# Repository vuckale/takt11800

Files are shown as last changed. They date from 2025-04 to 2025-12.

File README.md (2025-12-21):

# takt11800 - Compaq MX 11800 QMK/VIA Replacement PCB
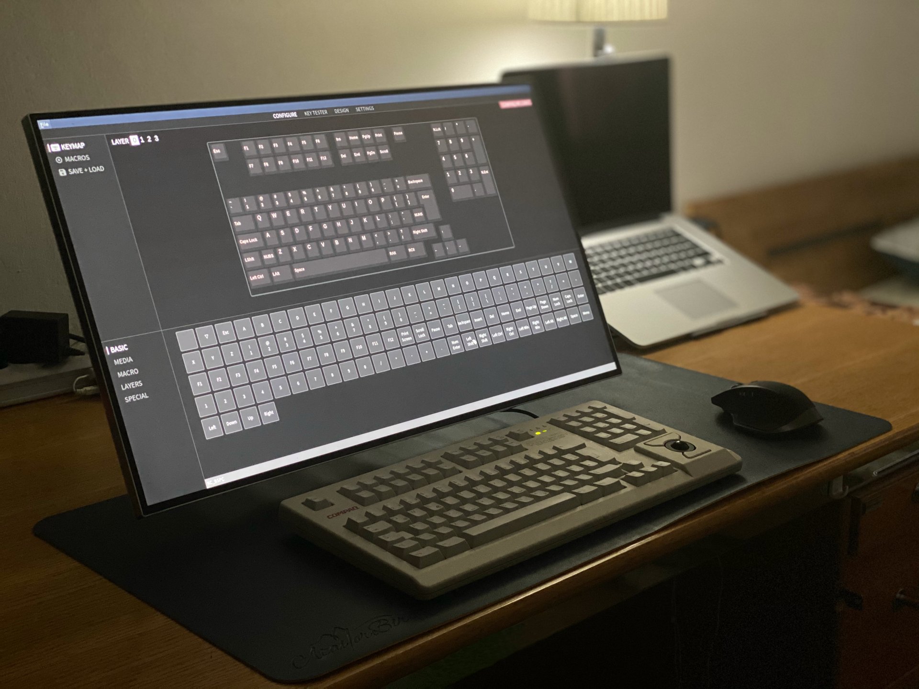
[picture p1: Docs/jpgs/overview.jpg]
Default Layout Overview


Sponsored by PCBWay - [Read More](#pcbway)

This project is a **drop-in replacement PCB** designed for the **Compaq MX 11800**, also known as the **Cherry G80-11800** a classic mechanical keyboard featuring **Cherry MX Brown switches** and an integrated **trackball**.

Originally designed for use in server rooms and rack-mounted setups, the MX 11800's **compact, space-saving layout** made it a go-to choice in enterprise environments.

### Project Features

- **Powered by QMK Firmware** – Fully customizable keymaps, layers, macros, and lighting effects.
- **VIA Support** – Seamless configuration through the user-friendly VIA interface.
- **Trackball Support** – Full functionality for the integrated pointing device.
- **Drop-In Compatible** – No case modifications required. Designed to fit directly into the original shell and work with original components.
- **USB-C Connectivity** – Modern convenience and reliability.

### Known Issues

During testing, the integrated trackball worked reliably with some MX 11800 variants (based on testing with a single German layout unit), but showed intermittent or unreliable behavior on others (such as international-layout versions). In some cases, the trackball would work inconsistently or fail to initialize.

At the time of writing, no reliable software solution has been found. Based on the observed behavior and the available hardware information, it is suspected that this may be related to a voltage level mismatch. The MCU operates at 3.3 V logic, while the original trackball assembly may expect 5 V logic levels. This has not yet been conclusively confirmed and remains under investigation.

A revised PCB is planned to address this potential issue at the hardware level. Until then, builders should be aware that trackball functionality may vary depending on the specific keyboard and trackball assembly used.

### BOM and CPL Orientation

The included BOM (Bill of Materials) and CPL (Component Placement List) are provided for orientation purposes. Depending on the assembly options selected and any variations in components, you may need to adjust these files when placing your order to ensure correct assembly.

### Why This Project?

The original MX 11800 has aged gracefully, but its internals were due for a modern upgrade. This replacement PCB brings this legendary board into the modern era while preserving its unique charm and functionality.

Whether you're a retro keyboard enthusiast, a server admin with a soft spot for classic gear, or just someone who loves trackball keyboards, this project gives new life to an iconic piece of hardware.

# Layout

## Default Layout
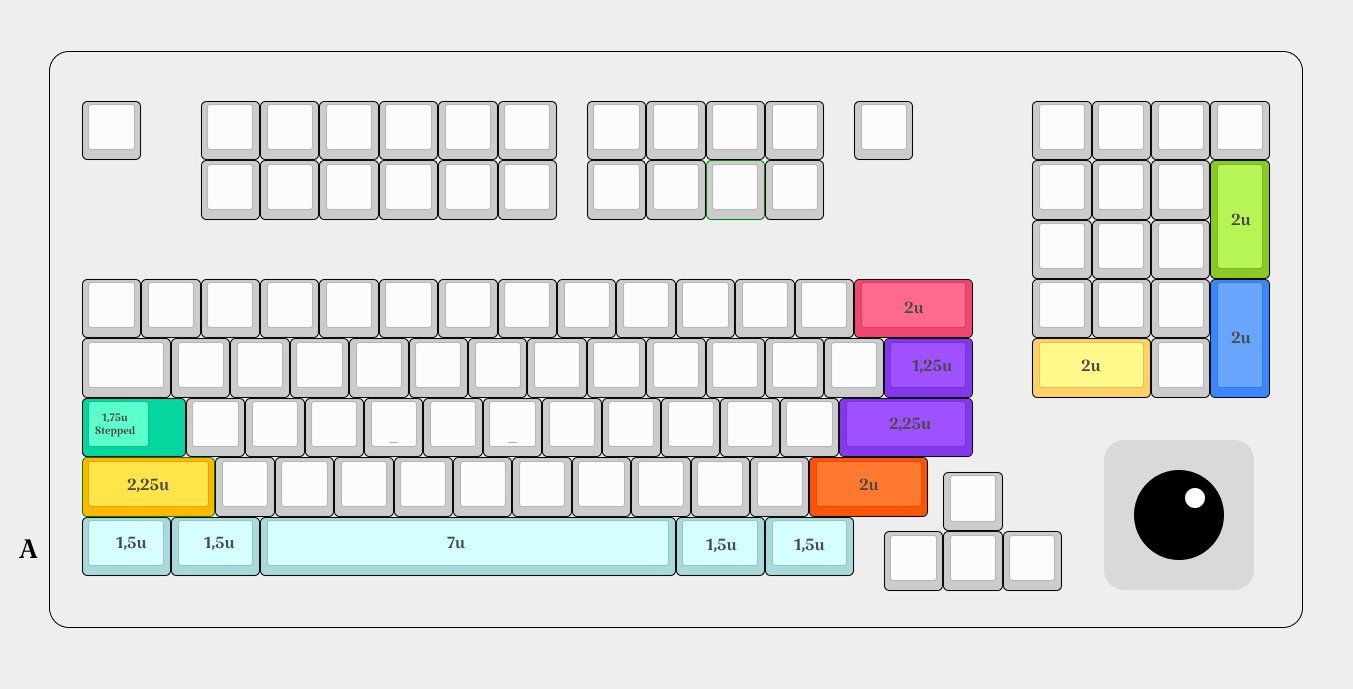
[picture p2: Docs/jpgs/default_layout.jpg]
Default Layout


This PCB supports multiple layout options. The previous image shows the default layout with colored keys and marked unit sizes that support alternate layouts. The default layout represents the configuration the keyboard is most commonly found in: ANSI enter with a 2.25u enter key, stepped caps lock, and a winkeyless 7u bottom row.

## Extended Layout
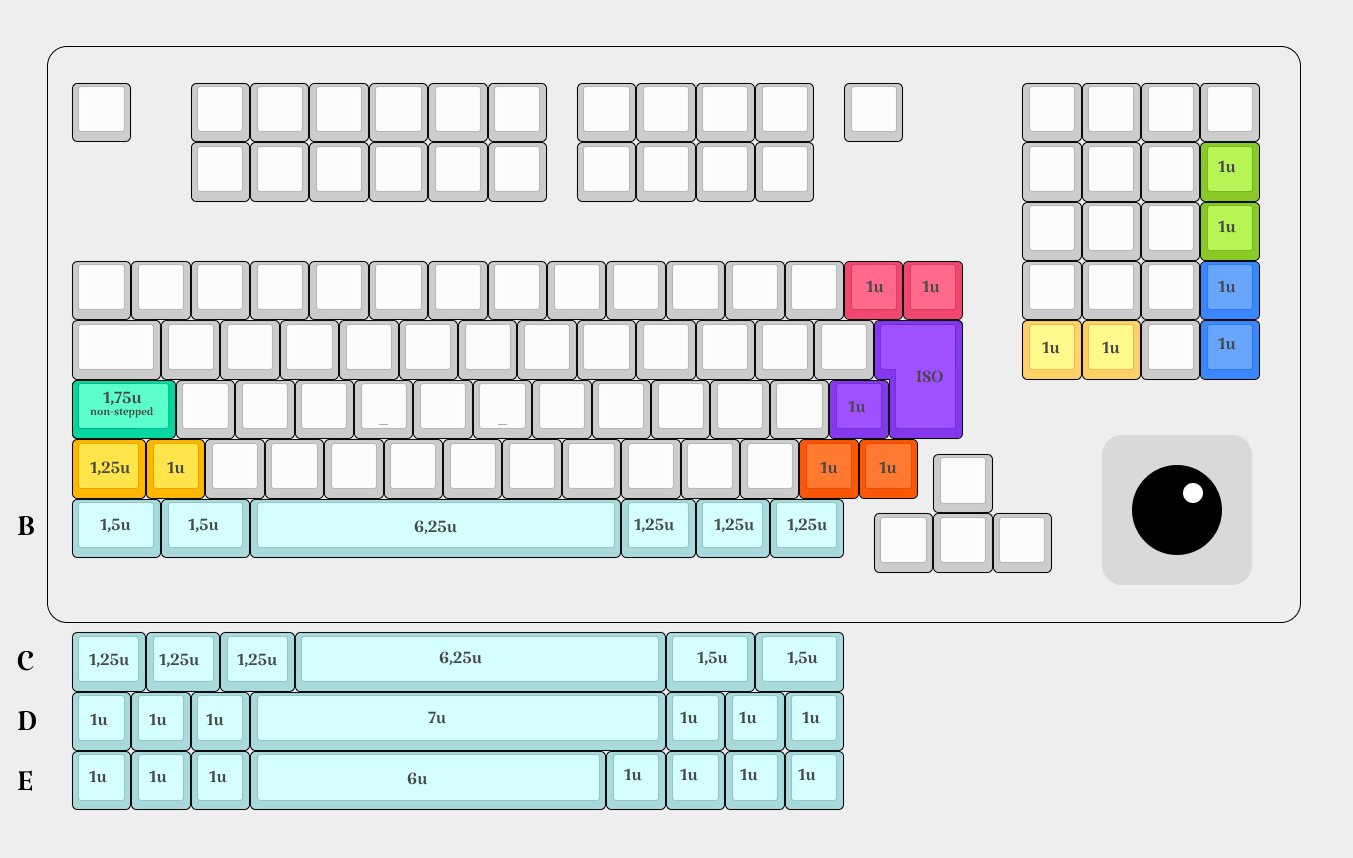
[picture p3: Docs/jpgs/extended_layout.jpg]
Extended Layout


The extended layout adds support for additional four bottom row variations, which are marked on the image with the letters b–e. For easier assembly, these are also labeled on the PCB itself, with unit sizes marked next to the switch holes and a–e marked on the stabilizer holes. Additionally, the extended layout supports a non-stepped caps lock key, ISO enter, split left shift and a backspace and 2u shift that can be split into two 1u keys. The numpad can also be converted into a full 1u macropad.

## PCB Overview
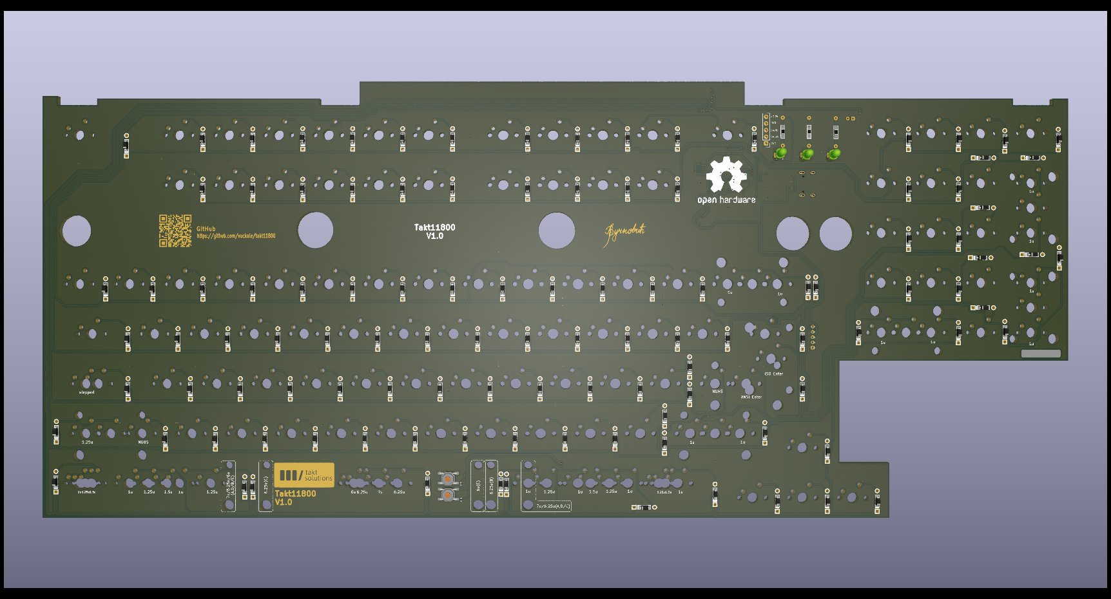
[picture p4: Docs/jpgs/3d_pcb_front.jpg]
Top View

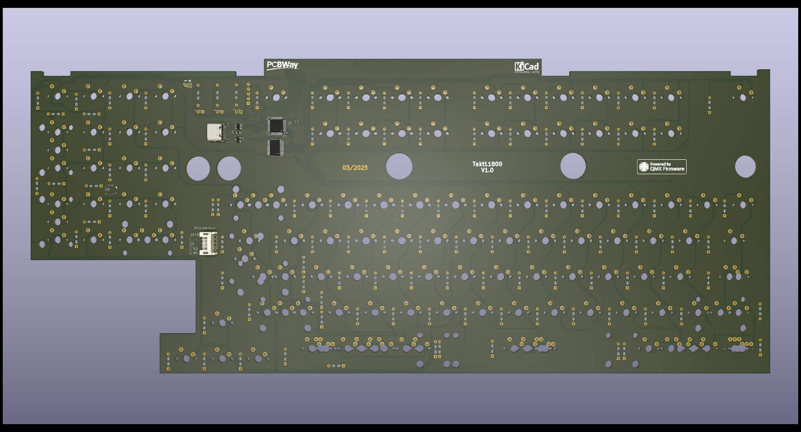
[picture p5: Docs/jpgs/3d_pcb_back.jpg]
Back View

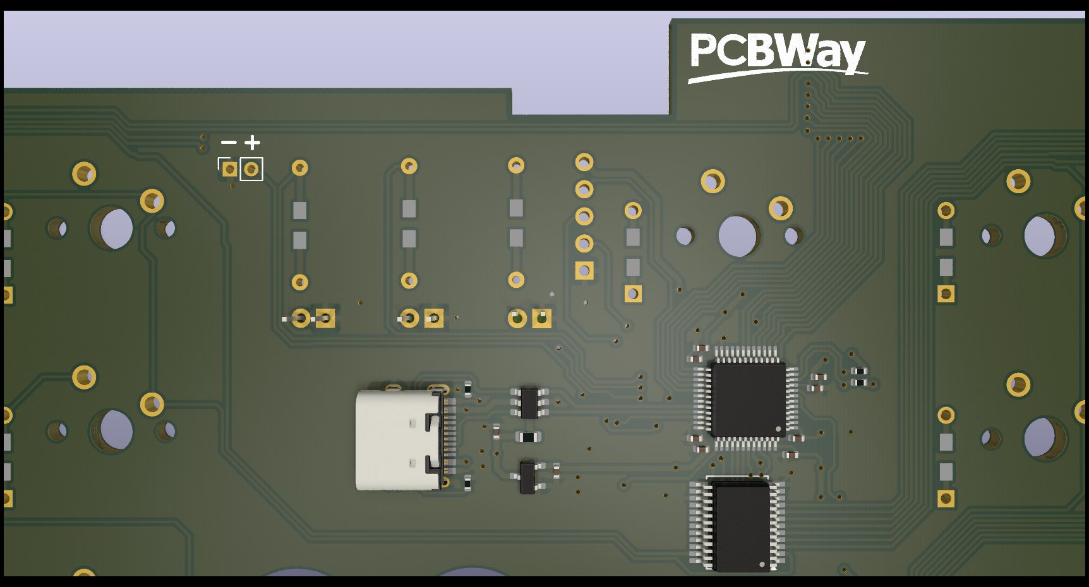
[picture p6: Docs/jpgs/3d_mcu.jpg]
MCU View

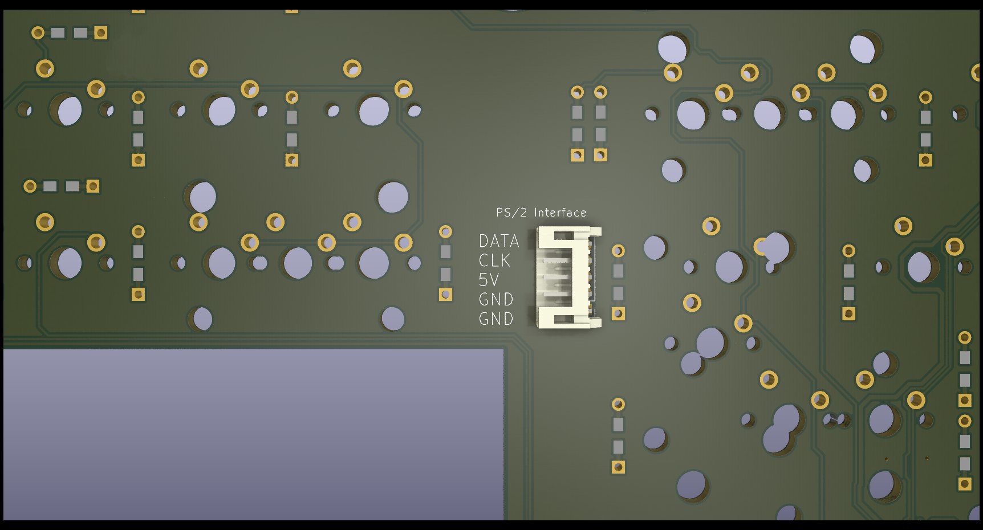
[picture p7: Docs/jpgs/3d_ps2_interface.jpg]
PS/2 Interface View


## PCBWay

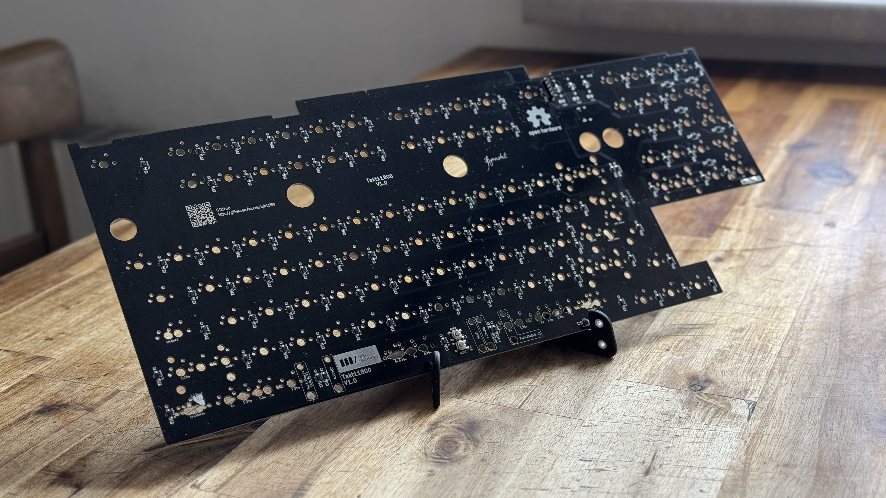
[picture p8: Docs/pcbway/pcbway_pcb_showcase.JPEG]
PCBWAY PCB Showcase


### Ordering Process

PCBWay made prototyping this PCB straightforward and easy. Their intuitive, beginner-friendly ordering process took all the guesswork out of manufacturing. I was impressed by how smoothly everything went, even on my first try. If you're curious to check it out or replicate the build, all the necessary files are neatly organized in the Fabrication Folder of this repository.

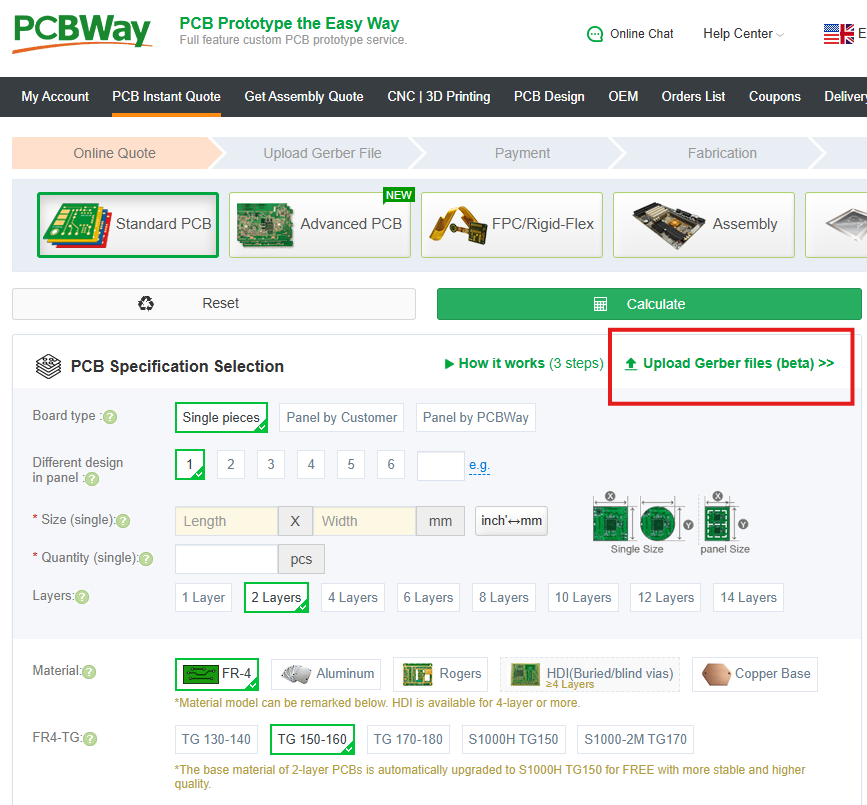
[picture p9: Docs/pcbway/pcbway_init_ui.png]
PCBWAY initial ui


Following the steps on their interface, placing an order with PCBWay was easy. After uploading the Gerber .zip file, the platform pre-filled many default values suitable for my 2-layer PCB, simplifying the process significantly. The only manual customization I initially made was changing the solder mask color to black—a purely aesthetic choice. However, PCBWay offers a wide range of specification options for those who want more control.

You can choose between single pieces, customer-designed panels, or panels assembled by PCBWay, and even combine different PCB designs within a single panel. Layer configurations are highly flexible, ranging from 1 up to 14 layers, with support for advanced materials like FR-4, Aluminum, and Rogers for high-frequency or thermal applications. PCB thickness can be set anywhere from 0.2 mm up to 3.2 mm, and you can define track/spacing resolutions as fine as 3/3 mil. For higher durability or signal performance, different finished copper weights are also available—ranging from bare copper to 12 oz Cu.

Solder mask colors include not only standard options like green, red, and blue, but also premium finishes like matte black and matte green. Silkscreen printing supports multiple colors (white, black, yellow) and even UV multi-color printing. Additional advanced options include edge connectors, various surface finishes like ENIG, immersion silver, and ENEPIG, and via treatments such as tenting, plugging, or open vias.

You also have the option to remove PCBWay's product number for a small fee, specify custom FR4-TG ratings, and opt for specialized features like castellated holes, edge plating, or impedance control. With all these configuration options, PCBWay caters not only to hobbyists but also to professionals needing precise and high-performance PCBs.

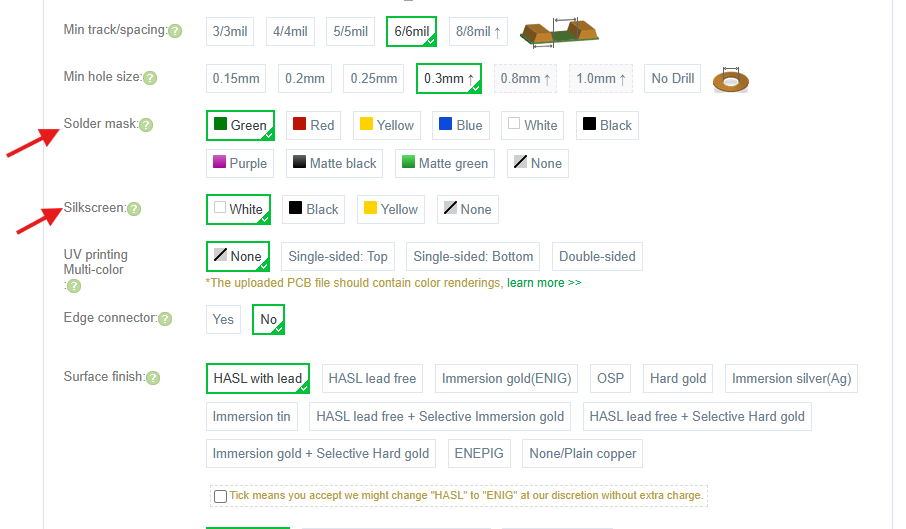
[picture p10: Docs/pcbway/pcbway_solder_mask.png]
PCBWAY solder mask color


For assembly, PCBWay provides a flexible set of options tailored to different needs: you can go with full turnkey assembly, where they source and solder everything; kitted/consigned, where you supply all the parts; or a combo option, where you send some components and let them handle the rest. 

For this project, I went with the full turnkey assembly—PCBWay not only assembled the boards but also sourced all the required components for me. This saved a huge amount of time and hassle, especially for parts that are hard to track down or have long lead times.

They also offer additional customization, like choosing whether to assemble single boards or panelized PCBs (recommended if you're doing runs of 20+ boards or working with small form factors), selecting top, bottom, or dual-sided assembly, and even specifying if you'd like to allow substitute components made in China—which I found useful for speeding up lead times without compromising quality.

Overall, their assembly service felt like a huge win—it was smooth, efficient, and let me focus entirely on design while they took care of the heavy lifting.

To do this, simply check the assembly option and fill in the necessary values as shown:

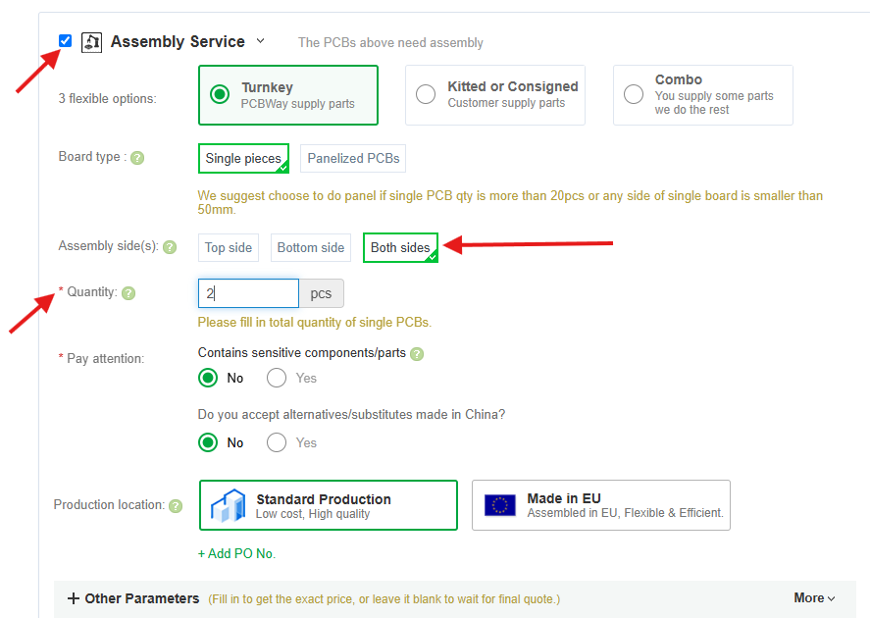
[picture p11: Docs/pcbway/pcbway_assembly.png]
PCBWAY assembly checkbox


After clicking "Save to Cart," you can upload the BOM, CPL, and component placement orientation files to complete your order.

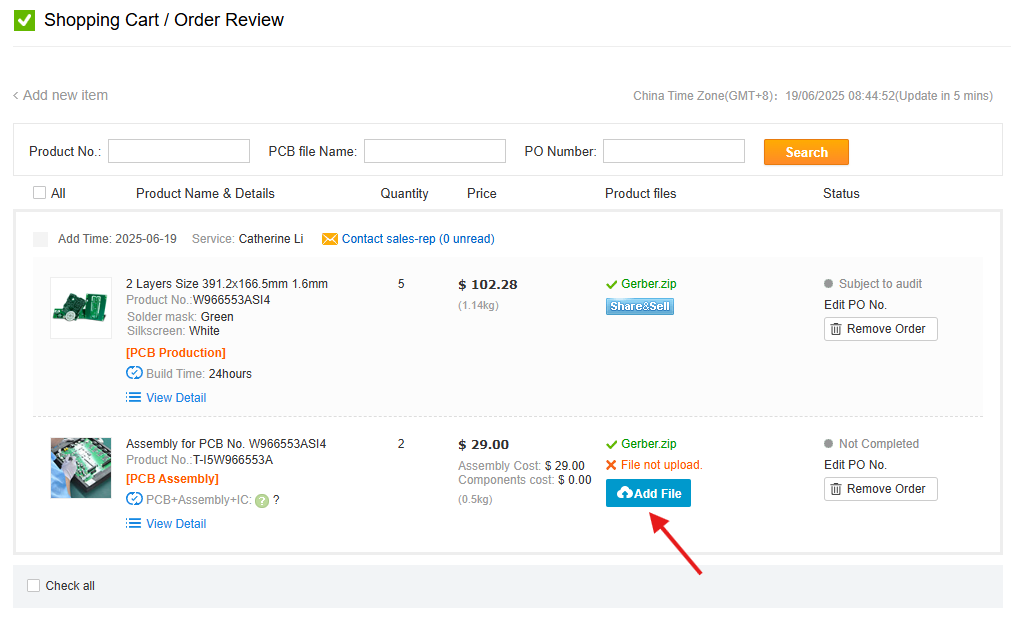
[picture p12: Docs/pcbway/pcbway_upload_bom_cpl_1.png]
PCBWAY Upload bom, cpl, and component placement orientation


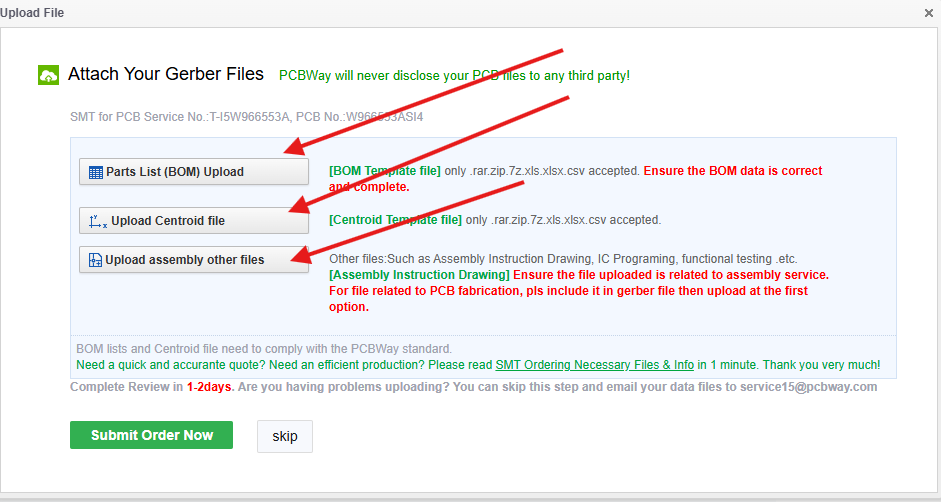
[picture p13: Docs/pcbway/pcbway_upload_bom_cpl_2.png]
PCBWAY Upload bom, cpl, and component placement orientation


After placing the order, I had frequent and helpful communication with their engineering team, who reached out to clarify a few design decisions and even helped me correct some mistakes in my Gerber files. I really appreciated how responsive and collaborative they were—it felt like working with a partner, not just a service provider.

One particularly thoughtful touch was that before final assembly and shipping, they sent me high-resolution photos of the finished PCBs for confirmation. This gave me a last opportunity to visually inspect the boards and ensure everything looked right—a great quality-control step that added to my confidence in the process.

Throughout production, PCBWay provides visual order tracking on their website, which shows exactly where your order is at every stage—file review, fabrication, solder mask, silkscreen, assembly, testing, and packaging. It’s clearly laid out and updated in real time, which made the waiting process far less stressful.

The total turnaround time was about two weeks, which included fabrication, full assembly, and component sourcing. When the package arrived, it was clear that shipping was handled with care: each board was sealed in an anti-static bag, then carefully wrapped with protective shrink wrap and cushioning to prevent any damage during transit.

Overall, the combination of attentive support, visual transparency, and high-quality results made the whole experience smooth and satisfying. I wouldn’t hesitate to work with them again on future prototypes.

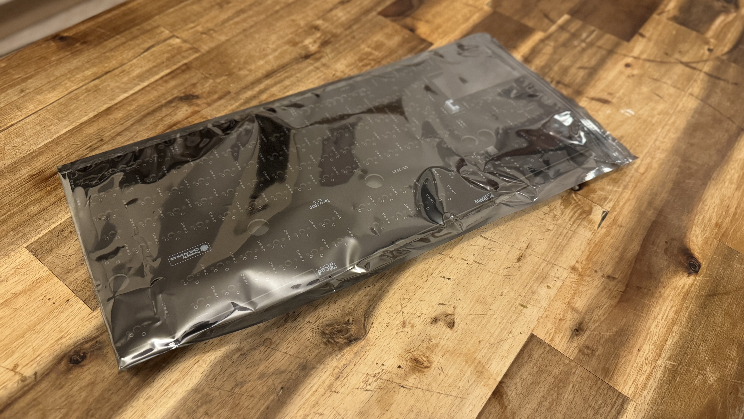
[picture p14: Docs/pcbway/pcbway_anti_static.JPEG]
PCBWAY package


### Quality

This is where PCBWay truly shines. I was impressed by the overall PCB quality—the solder mask is perfectly uniform and consistent throughout. In my design, I included both silkscreen text and exposed copper text by selectively removing the top solder mask, and both came out flawless, with crisp details and no smudging or misalignment.

The components—including the MCU, SMD resistors, capacitors, and others—are perfectly placed, with flawless solder joints even on the tiniest parts. I’ll let the image speak for itself.

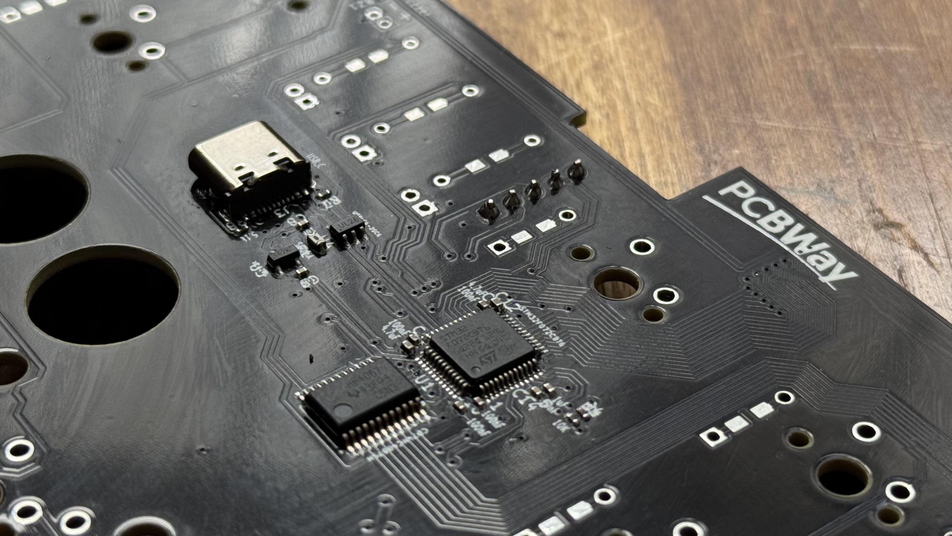
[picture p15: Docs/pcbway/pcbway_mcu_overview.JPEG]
PCBWAY MCU and other components


The plated through-holes on this PCB are clean, well-aligned, and have excellent copper coverage—perfect for reliable soldering. 

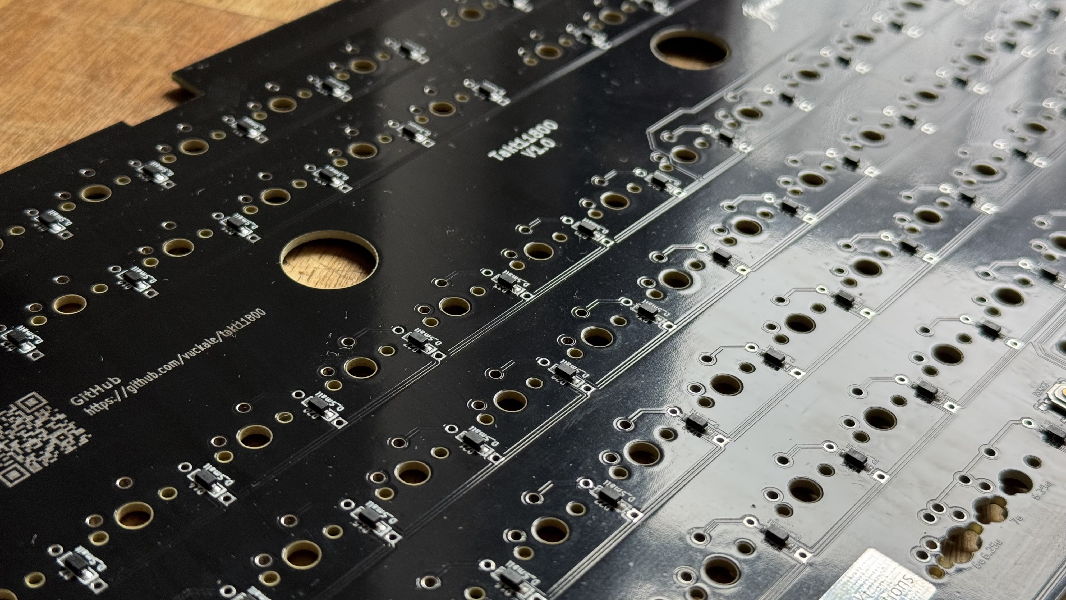
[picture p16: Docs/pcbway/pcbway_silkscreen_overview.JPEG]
PCBWAY solder mask and silk screen


### Assembly

After soldering the switches and plugging in the trackball, all that was left was flashing the firmware. The STM32 chips come pre-flashed with a bootloader, so once connected to the PC, holding the BOOT switch and tapping NRST puts the board into flashing mode—simple as that.

The build includes 105 switches, and for a standard ISO layout, it uses 6× 2u stabilizers and 1× 7u stabilizer, though this may vary depending on the chosen layout.

### Final Words

Overall, working with PCBWay was a smooth and satisfying experience. The ordering process was easy, communication was fast and helpful, and the visual tracking kept me updated every step of the way. With a quick two-week turnaround, high-quality fabrication, flawless assembly, and great attention to detail, PCBWay delivered a professional result I’d gladly rely on again.

## License

This project is licensed under the **CERN Open Hardware Licence Version 2 - Strongly Reciprocal (CERN-OHL-S)**.

You are free to use, study, modify, and distribute the design files and products based on them, as long as any distributed modifications or derivative works are also released under the same license.

For the full license text, see the [LICENSE](LICENSE) file in this repository or visit the [official CERN OHL v2 page](https://gitlab.com/ohwr/project/cernohl/-/wikis/uploads/b236492596cfc91c12def7d50bbf7da0/cern_ohl_s_v2.pdf).

(C) 2025 [Aleksandar Vuckovic]

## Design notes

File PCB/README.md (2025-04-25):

# This is **Work In Progress**

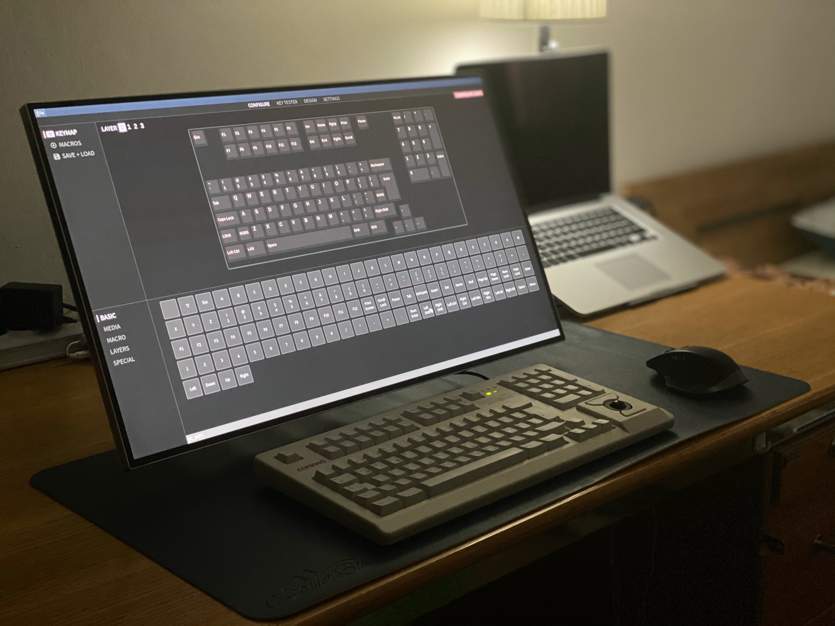
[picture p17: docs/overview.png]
va11800-pcb

va11800-pcb
va11800-pcb
va11800-pcb
va11800-matrix

Required **[Daughterboard repository](https://github.com:vuckale/va11800-daughterboard)**

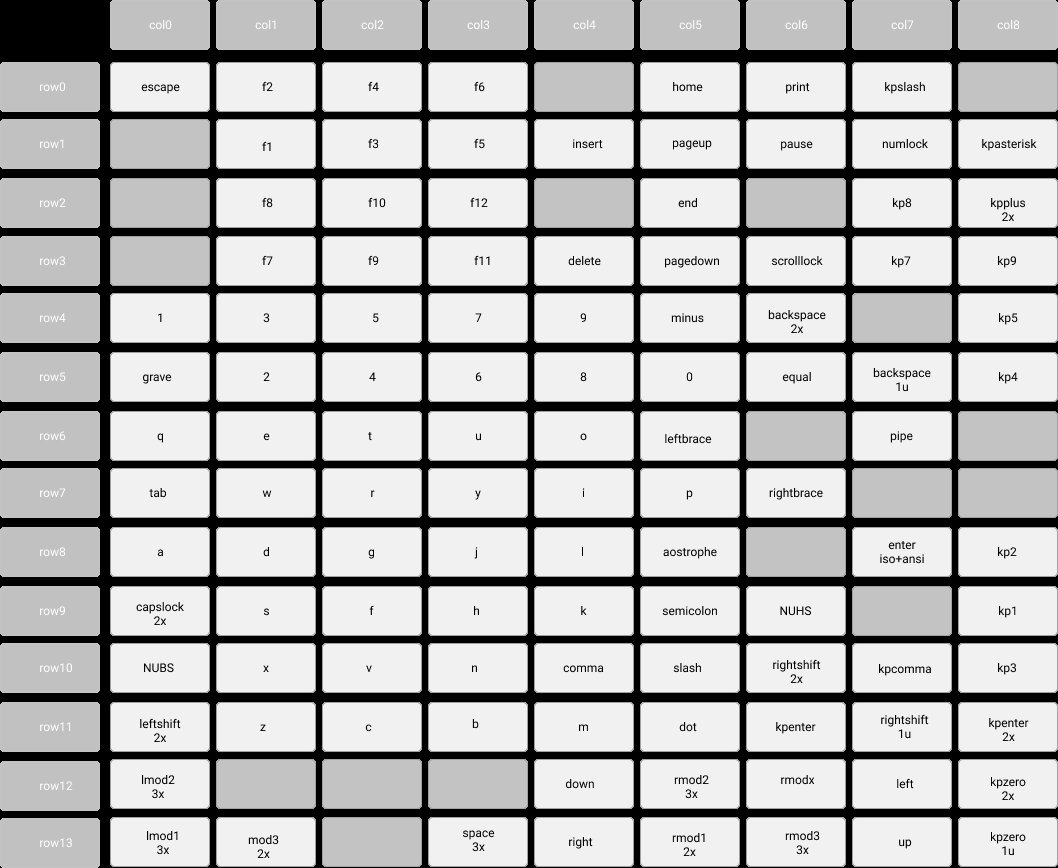
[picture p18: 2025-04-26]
Docs/jpgs/matrix.jpg

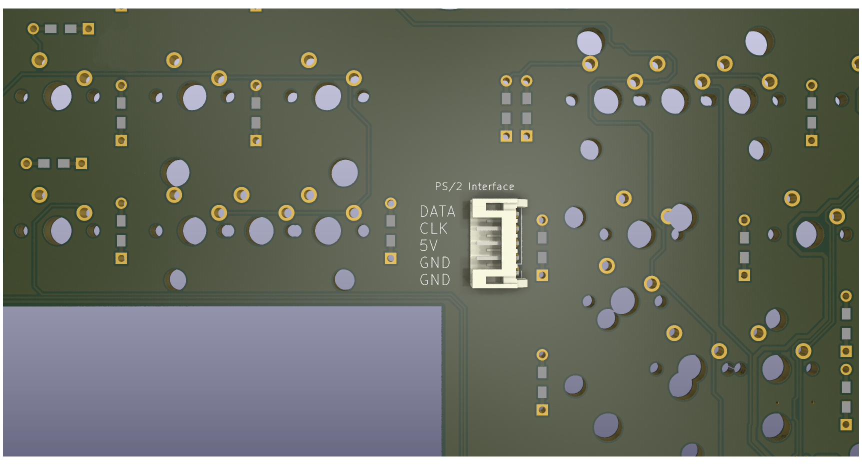
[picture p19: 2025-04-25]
Docs/pngs/3d_ps2_interface.png

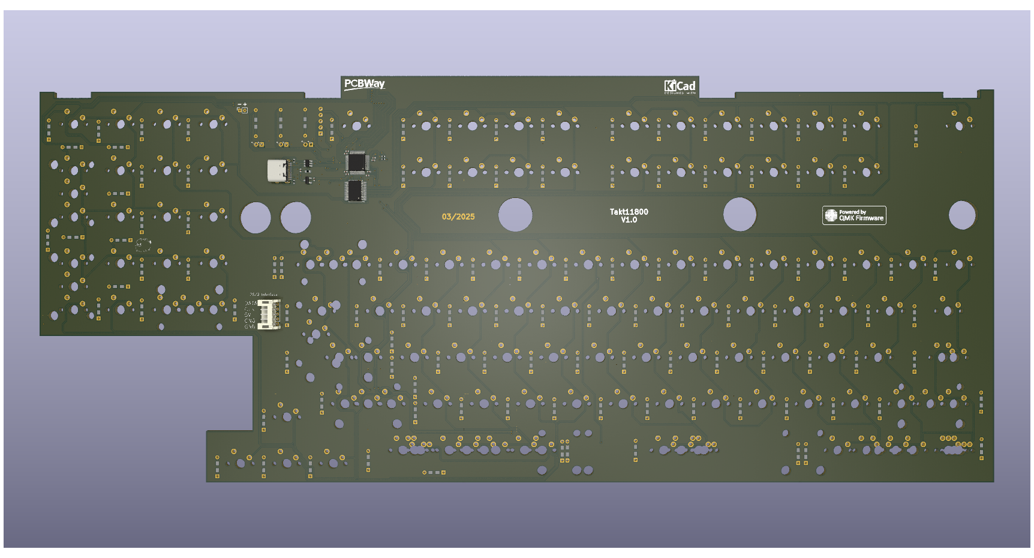
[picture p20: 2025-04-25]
Docs/pngs/3d_pcb_back.png

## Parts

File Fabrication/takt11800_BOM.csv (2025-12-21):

Item # | *Designator | *Qty | Manufacturer | *Mfg Part # | Description / Value | *Package/Footprint | Type | Your Instructions / Notes
1 | D1,D2,D3,D4,D5,D6,D7,D8,D9,D10,D11,D12,D13,D14,D15,D16,D17,D18,D19,D20,D21,D22,D23,D24,D25,D26,D27,D28,D29,D30,D31,D32,D33,D34,D35,D36,D37,D38,D39,D40,D41,D42,D43,D44,D45,D46,D47,D48,D49,D50,D51,D52,D53,D54,D56,D57,D58,D59,D60,D61,D62,D64,D65,D66,D67,D68,D69,D70,D72,D73,D74,D75,D76,D77,D78,D79,D80,D81,D82,D83,D84,D85,D86,D87,D88,D89,D90,D91,D92,D93,D94,D95,D96,D97,D98,D99,D100,D101,D102,D103,D104,D105,D106,D107,D108,D109,D110,D111,D112,D113,D114 | 111 | Shandong Jingdao Microelectronics | 1N4148W | 100V Independent Type 1.25V@150mA 8ns 300mA SOD-123 Switching Diodes ROHS | SOD-123 | SMD | JLCPCB Part # C115103
2 | U1 | 1 | STMicroelectronics | STM32F072CBT6 | 128KB 1.65V~3.6V ARM-M0 16KB 48MHz FLASH 37 LQFP-48(7x7) Microcontrollers (MCU/MPU/SOC) ROHS | LQFP-48(7x7) | SMD | JLCPCB Part # C81720
3 | U2 | 1 | Texas Instruments | CD74HC4067SM96 | SSOP-24-208mil Analog Switches, Multiplexers ROHS | SSOP-24-208mil | SMD | JLCPCB Part # C98457
4 | U3 | 1 | Torex Semicon | XC6206P332MR-G | 200mA Fixed 3.3V Positive electrode 6V SOT-23-3L Voltage Regulators - Linear, Low Drop Out (LDO) Regulators ROHS | SOT-23-3L | SMD | JLCPCB Part # C5446
5 | U4 | 1 | TECH PUBLIC | USBLC6-2SC6 | 6A 12V 150W 6V Unidirectional 5V SOT-23-6 ESD and Surge Protection (TVS/ESD) ROHS | SOT-23-6 | SMD | JLCPCB Part # C2827654
6 | C8,C9,C15 | 3 | Samsung Electro-Mechanics | CL05A105KA5NQNC | 25V 1uF X5R �10% 0402 Multilayer Ceramic Capacitors MLCC - SMD/SMT ROHS | 0402 | SMD | JLCPCB Part # C52923
7 | C10,C11,C13,C16,C18 | 5 | Samsung Electro-Mechanics | CL05B104KB54PNC | 50V 100nF X7R �10% 0402 Multilayer Ceramic Capacitors MLCC - SMD/SMT ROHS | 0402 | SMD | JLCPCB Part # C307331
8 | C12,C17 | 2 | Samsung Electro-Mechanics | CL05A475MP5NRNC | 10V 4.7uF X5R �20% 0402 Multilayer Ceramic Capacitors MLCC - SMD/SMT ROHS | 0402 | SMD | JLCPCB Part # C23733
9 | C14 | 1 | Samsung Electro-Mechanics | CL05B103KB5NNNC | 50V 10nF X7R �10% 0402 Multilayer Ceramic Capacitors MLCC - SMD/SMT ROHS | 0402 | SMD | JLCPCB Part # C15195
10 | F1 | 1 | BOURNS | MF-FSMF050X-2 | 6V 500mA 40A 1A 0603 Resettable Fuses ROHS | 0603 | SMD | JLCPCB Part # C210357
11 | J3 | 1 | Global Connector Technology | USB4800-03-A | SMD USB Connectors ROHS | SMD | SMD | JLCPCB Part # C5352763
12 | R1,R2,R3 | 3 | UNI-ROYAL(Uniroyal Elec) | 0805W8F2200T5E | 125mW Thick Film Resistors 150V �100ppm/? �1% 220? 0805 Chip Resistor - Surface Mount ROHS | 0805 | SMD | JLCPCB Part # C17557
13 | R4,R5, R6 | 3 | UNI-ROYAL(Uniroyal Elec) | 0402WGF1002TCE | 62.5mW Thick Film Resistors 50V �100ppm/? �1% 10k? 0402 Chip Resistor - Surface Mount ROHS | 0402 | SMD | JLCPCB Part # C25744
14 | R7,R8 | 2 | UNI-ROYAL(Uniroyal Elec) | 0402WGF5101TCE | 62.5mW Thick Film Resistors 50V �100ppm/? �1% 5.1k? 0402 Chip Resistor - Surface Mount ROHS | 0402 | SMD | JLCPCB Part # C25905
15 | SW1, SW2 | 2 | ALPSALPINE | SKQGABE010 | 5.2mm 1.5mm Round Button 50mA Standing paste 5.2mm SPST 12V SMD Tactile Switches ROHS | SMD | SMD | JLCPCB Part # C115351

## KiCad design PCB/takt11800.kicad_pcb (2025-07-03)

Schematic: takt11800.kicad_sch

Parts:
BZ1: Buzzer; PinSocket_1x02_P2.00mm_Vertical
C8, C9: 1uF; Capacitor_0402; LCSC C52923
C10, C11, C13, C16: 100nF; Capacitor_0402; MPN CL05B104KB54PNC; LCSC C307331
C12, C17: 4.7uF; Capacitor_0402; MPN CL05A475MP5NRNC; LCSC C23733
C14: 10nF; Capacitor_0402; MPN CL05B103KB5NNNC; LCSC C15195
C15: 1uF; Capacitor_0402; MPN CL05A105KA5NQNC; LCSC C52923
C18: 100nF; Capacitor_0402; LCSC C307331
D1, D2, D3, D4, D5, D6, D7, D8, D9, D10, D11, D12, D13, D14, D15, D16, D17, D18, D19, D20, D21, D22, D23, D24, D25, D26, D27, D28, D29, D30, D31, D32, D33, D34, D35, D36, D37, D38, D39, D40, D41, D42, D43, D44, D45, D46, D47, D48, D49, D50, D51, D52, D53, D54, D56, D57, D58, D59, D60, D61, D62, D64, D65, D66, D67, D68, D69, D70, D72, D73, D74, D75, D76, D77, D78, D79, D80, D81, D82, D83, D84, D85, D86, D87, D88, D89, D90, D91, D92, D93, D94, D95, D96, D97, D98, D99, D100, D101, D102, D103, D104, D105, D106, D107, D108, D109, D110, D111, D112, D113, D114: D_Small; Diode-dual; LCSC C115103
D55, D63, D71: LED; LED_D2.00mm
F1: 500mA; Fuse_0603; LCSC C210357
H1, H2, H3, H4, H5: MountingHole; MountingHole_3.2mm_M3
J1: Conn_01x05; PinHeader_1x05_P2.54mm_Vertical
J2: USB4800-03-A; CONN_USB4800_GCT
J4: Conn_01x05_Pin; PinHeader_1x05_P2.00mm_Vertical
NUBS-key1: MX-NoLED; MXOnly-1U-NoLED
NUHS-key1: MX-NoLED; MXOnly-1U-NoLED
R1, R2, R3: 0.22K; Resistor
R4, R5: 10K; Resistor_0402
R6: 10k; Resistor_0402; LCSC C25744
R7, R8: 5.1k; Resistor_0402; LCSC C25905
SW1: BOOT; Button_TL3342; LCSC C115351
SW2: NRST; Button_TL3342; LCSC C115351
U1: STM32F072CBT6; Package_LQFP-48_7x7mm_P0.5; LCSC C81720
U2: CD74HC4067SM; SSOP-24_5.3x8.2mm_P0.65mm
U3: XC6206; Voltage_SOT-23; LCSC C5446
U4: USBLC6-2SC6; ESD_SOT-23-6; LCSC C2827654
a-key1: MX-NoLED; MXOnly-1U-NoLED
apostrophe-key1: MX-NoLED; MXOnly-1U-NoLED
arrow-down-key1: MX-NoLED; MXOnly-1U-NoLED
arrow-left-key1: MX-NoLED; MXOnly-1U-NoLED
arrow-right-key1: MX-NoLED; MXOnly-1U-NoLED
arrow-up-key1: MX-NoLED; MXOnly-1U-NoLED
b-key1: MX-NoLED; MXOnly-1U-NoLED
backspace1-key1, backspace3-key1: MX-NoLED; MXOnly-1U-NoLED
backspace2-key1: MX-NoLED; MXOnly-2U-ReversedStabilizers-NoLED
c-key1: MX-NoLED; MXOnly-1U-NoLED
capslock-standard-key1: MX-NoLED; MXOnly-1.75U-NoLED
capslock-stepped-key1: MX-NoLED; MXOnly-1.25U-NoLED
comma-key1: MX-NoLED; MXOnly-1U-NoLED
delete-Key1: MX-NoLED; MXOnly-1U-NoLED
dot-key1: MX-NoLED; MXOnly-1U-NoLED
e-key1: MX-NoLED; MXOnly-1U-NoLED
end-Key1: MX-NoLED; MXOnly-1U-NoLED
enter-ANSI-key1: MX-NoLED; MXOnly-2.25U-NoLED
enter-ISO-key1: MX-NoLED; MXOnly-ISO-ReversedStabilizers-NoLED
equal-key1: MX-NoLED; MXOnly-1U-NoLED
escape-Key1: MX-NoLED; MXOnly-1U-NoLED
f1-Key1, f2-Key1, f3-Key1, f4-Key1, f5-Key1, f6-Key1, f7-Key1, f8-Key1, f9-Key1, f10-Key1, f11-Key1, f12-Key1: MX-NoLED; MXOnly-1U-NoLED
f-key1: MX-NoLED; MXOnly-1U-NoLED
g-key1: MX-NoLED; MXOnly-1U-NoLED
grave-key1: MX-NoLED; MXOnly-1U-NoLED
h-key1: MX-NoLED; MXOnly-1U-NoLED
home-Key1: MX-NoLED; MXOnly-1U-NoLED
i-key1: MX-NoLED; MXOnly-1U-NoLED
insert-Key1: MX-NoLED; MXOnly-1U-NoLED
j-key1: MX-NoLED; MXOnly-1U-NoLED
k-key1: MX-NoLED; MXOnly-1U-NoLED
key_d1: MX-NoLED; MXOnly-1U-NoLED
kp_#0-1U-left-key1, kp_#0-1U-right-key1, kp_#2-key1, kp_#2-key2, kp_#3-key1, kp_#4-key1, kp_#5-key1, kp_#6-key1, kp_#8-key1, kp_#9-key1: MX-NoLED; MXOnly-1U-NoLED
kp_#0-2U-key1: MX-NoLED; MXOnly-2U-ReversedStabilizers-NoLED
kp_#7-key1: MX_NoLED; MXOnly-1U-NoLED
kp_comma-key1: MX-NoLED; MXOnly-1U-NoLED
kp_divide-key1: MX-NoLED; MXOnly-1U-NoLED
kp_enter-1U-down-key1, kp_enter-1U-top-key1: MX-NoLED; MXOnly-1U-NoLED
kp_enter-2U-key1: MX-NoLED; MXOnly-2U-VerticalStabilizers-NoLED
kp_minus-key1: MX-NoLED; MXOnly-1U-NoLED
kp_plus1-key1: MX-NoLED; MXOnly-2U-VerticalStabilizers-NoLED
kp_plus2-key1: MX-NoLED; MXOnly-1U-NoLED
kp_plus-1U-down-key1: MX-NoLED; MXOnly-1U-NoLED
kp_times-key1: MX-NoLED; MXOnly-1U-NoLED
l-key1: MX-NoLED; MXOnly-1U-NoLED
left-mod1-1.5U-key1, left-mod2-1.5U-key1: MX-NoLED; MXOnly-1.5U-NoLED
left-mod1-1.25U-key1, left-mod2-1.25U-key1, left-mod3-1.25U-key1: MX-NoLED; MXOnly-1.25U-NoLED
left-mod1-1U-key1, left-mod2-1U-key1, left-mod3-1U-key1: MX-NoLED; MXOnly-1U-NoLED
left_shift-1.25U-key1: MX-NoLED; MXOnly-1.25U-NoLED
left_shift-2.25U-key1: MX-NoLED; MXOnly-2.25U-NoLED
leftbrace-key1: MX-NoLED; MXOnly-1U-NoLED
m-key1: MX-NoLED; MXOnly-1U-NoLED
minus-key1: MX-NoLED; MXOnly-1U-NoLED
n0, n1, n2, n3, n4, n5, n6, n7, n8, n9: MX-NoLED; MXOnly-1U-NoLED
n-key1: MX-NoLED; MXOnly-1U-NoLED
numlock-Key1: MX-NoLED; MXOnly-1U-NoLED
o-key1: MX-NoLED; MXOnly-1U-NoLED
p-key1: MX-NoLED; MXOnly-1U-NoLED
pagedown-Key1: MX-NoLED; MXOnly-1U-NoLED
pageup-Key1: MX-NoLED; MXOnly-1U-NoLED
pause-Key1: MX-NoLED; MXOnly-1U-NoLED
pipe-key1: MX-NoLED; MXOnly-1.5U-NoLED
print-Key1: MX-NoLED; MXOnly-1U-NoLED
q-key1: MX-NoLED; MXOnly-1U-NoLED
r-key1: MX-NoLED; MXOnly-1U-NoLED
right-mod1-1.5U-key1, right-mod2-1.5U-key1: MX-NoLED; MXOnly-1.5U-NoLED
right-mod1-1.25U-key1, right-mod2-1.25U-key1, right-mod3-1.25U-key1: MX-NoLED; MXOnly-1.25U-NoLED
right-mod1-1U-key1, right-mod2-1U-key1, right-mod3-1U-key1, right-mod4-1U-key1: MX-NoLED; MXOnly-1U-NoLED
right_shift-1U-left-key1, right_shift-1U-right-key1: MX-NoLED; MXOnly-1U-NoLED
right_shift-2U-key1: MX-NoLED; MXOnly-2U-NoLED
rightbrace-key1: MX-NoLED; MXOnly-1U-NoLED
s-key1: MX-NoLED; MXOnly-1U-NoLED
scroll_lock-Key1: MX-NoLED; MXOnly-1U-NoLED
semicolon-key1: MX-NoLED; MXOnly-1U-NoLED
slash-key1: MX-NoLED; MXOnly-1U-NoLED
space-6.25-C-key1, space-6.25U-B-key1: MX-NoLED; MXOnly-6.25U-NoLED
space-6U1: MX-NoLED; MXOnly-6U-Centered-NoLED
space-6U/7U-key1: MX-NoLED; MXOnly-7U-NoLED
t-key1: MX-NoLED; MXOnly-1U-NoLED
tab-key1: MX-NoLED; MXOnly-1.5U-NoLED
u-key1: MX-NoLED; MXOnly-1U-NoLED
v-key1: MX-NoLED; MXOnly-1U-NoLED
w-key1: MX-NoLED; MXOnly-1U-NoLED
x-key1: MX-NoLED; MXOnly-1U-NoLED
y-key1: MX-NoLED; MXOnly-1U-NoLED
z-key1: MX-NoLED; MXOnly-1U-NoLED

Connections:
+3.3V: C9.1, C10.2, C11.2, C12.2, C13.2, C14.2, C15.2, C16.2, C17.2, J1.5, R4.2, R5.2, SW1.1, U1.1 (VBAT), U1.9 (VDDA), U1.24 (VDD), U1.36 (VDDIO2), U1.48 (VDD), U2.24 (VCC), U3.2 (VO)
+5V: C8.1, F1.2, J4.3, U3.3 (VI)
/A9: U1.30 (PA9)
/A10: U1.31 (PA10)
/B2: U1.20 (PB2)
/BOOT0: R6.2, SW1.2, U1.44 (BOOT0)
/C14: U1.3 (PC14)
/C15: U1.4 (PC15)
/F0: U1.5 (PF0)
/F1: U1.6 (PF1)
/MCU_D+: U1.33 (PA12), U4.1 (I/O1)
/MCU_D-: U1.32 (PA11), U4.3 (I/O2)
/NRST: C18.2, SW2.2, U1.7 (NRST)
/USB_D+: J2.A6 (DP1), J2.B6 (DP2), U4.6 (I/O1)
/USB_D-: J2.A7 (DN1), J2.B7 (DN2), U4.4 (I/O2)
CLK: J4.4, R5.1, U1.10 (PA0)
CapsLock: R2.2, U1.21 (PB10)
DATA: J4.5, R4.1, U1.11 (PA1)
GND: BZ1.1 (+), C8.2, C9.2, C10.1, C11.1, C12.1, C13.1, C14.1, C15.1, C16.1, C17.1, C18.1, D55.1 (K), D63.1 (K), D71.1 (K), J1.1, J2.A1 (GND), J2.A12 (GND), J2.B1 (GND), J2.B12 (GND), J4.1, J4.2, R6.1, R7.2, R8.1, SW2.1, U1.8 (VSSA), U1.23 (VSS), U1.35 (VSS), U1.47 (VSS), U2.12 (GND), U2.15 (~E), U3.1 (GND), U4.2 (GND)
unnamed: D1.2 (A), left-mod1-1.5U-key1.2 (ROW), left-mod1-1.25U-key1.2 (ROW), left-mod1-1U-key1.2 (ROW)
unnamed: D2.2 (A), escape-Key1.2 (ROW)
unnamed: D4.2 (A), tab-key1.2 (ROW)
unnamed: D5.2 (A), capslock-standard-key1.2 (ROW), capslock-stepped-key1.2 (ROW)
unnamed: D6.2 (A), left_shift-1.25U-key1.2 (ROW), left_shift-2.25U-key1.2 (ROW)
unnamed: D7.2 (A), n1.2 (ROW)
unnamed: D8.2 (A), q-key1.2 (ROW)
unnamed: D9.2 (A), a-key1.2 (ROW)
unnamed: D10.2 (A), NUBS-key1.2 (ROW)
unnamed: D11.2 (A), left-mod2-1.5U-key1.2 (ROW), left-mod2-1.25U-key1.2 (ROW), left-mod2-1U-key1.2 (ROW)
unnamed: D12.2 (A), f1-Key1.2 (ROW)
unnamed: D13.2 (A), f7-Key1.2 (ROW)
unnamed: D14.2 (A), n2.2 (ROW)
unnamed: D15.2 (A), w-key1.2 (ROW)
unnamed: D16.2 (A), s-key1.2 (ROW)
unnamed: D17.2 (A), z-key1.2 (ROW)
unnamed: D18.2 (A), f2-Key1.2 (ROW)
unnamed: D19.2 (A), f8-Key1.2 (ROW)
unnamed: D20.2 (A), n3.2 (ROW)
unnamed: D21.2 (A), e-key1.2 (ROW)
unnamed: D22.2 (A), key_d1.2 (ROW)
unnamed: D23.2 (A), x-key1.2 (ROW)
unnamed: D24.2 (A), left-mod3-1.25U-key1.2 (ROW), left-mod3-1U-key1.2 (ROW)
unnamed: D25.2 (A), f3-Key1.2 (ROW)
unnamed: D26.2 (A), f9-Key1.2 (ROW)
unnamed: D27.2 (A), n4.2 (ROW)
unnamed: D28.2 (A), r-key1.2 (ROW)
unnamed: D29.2 (A), f-key1.2 (ROW)
unnamed: D30.2 (A), c-key1.2 (ROW)
unnamed: D31.2 (A), f4-Key1.2 (ROW)
unnamed: D32.2 (A), f10-Key1.2 (ROW)
unnamed: D33.2 (A), n5.2 (ROW)
unnamed: D34.2 (A), t-key1.2 (ROW)
unnamed: D35.2 (A), g-key1.2 (ROW)
unnamed: D36.2 (A), v-key1.2 (ROW)
unnamed: D37.2 (A), f5-Key1.2 (ROW)
unnamed: D38.2 (A), n6.2 (ROW)
unnamed: D39.2 (A), y-key1.2 (ROW)
unnamed: D40.2 (A), h-key1.2 (ROW)
unnamed: D41.2 (A), b-key1.2 (ROW)
unnamed: D42.2 (A), space-6.25-C-key1.2 (ROW), space-6.25U-B-key1.2 (ROW), space-6U1.2 (ROW), space-6U/7U-key1.2 (ROW)
unnamed: D43.2 (A), f11-Key1.2 (ROW)
unnamed: D44.2 (A), f6-Key1.2 (ROW)
unnamed: D45.2 (A), f12-Key1.2 (ROW)
unnamed: D46.2 (A), n7.2 (ROW)
unnamed: D47.2 (A), u-key1.2 (ROW)
unnamed: D48.2 (A), j-key1.2 (ROW)
unnamed: D49.2 (A), n-key1.2 (ROW)
unnamed: D50.2 (A), arrow-right-key1.2 (ROW)
unnamed: D51.2 (A), n8.2 (ROW)
unnamed: D52.2 (A), i-key1.2 (ROW)
unnamed: D53.2 (A), k-key1.2 (ROW)
unnamed: D54.2 (A), m-key1.2 (ROW)
unnamed: D55.2 (A), R1.1
unnamed: D56.2 (A), insert-Key1.2 (ROW)
unnamed: D57.2 (A), delete-Key1.2 (ROW)
unnamed: D58.2 (A), n9.2 (ROW)
unnamed: D59.2 (A), o-key1.2 (ROW)
unnamed: D60.2 (A), l-key1.2 (ROW)
unnamed: D61.2 (A), comma-key1.2 (ROW)
unnamed: D62.2 (A), arrow-down-key1.2 (ROW)
unnamed: D63.2 (A), R2.1
unnamed: D64.2 (A), home-Key1.2 (ROW)
unnamed: D65.2 (A), end-Key1.2 (ROW)
unnamed: D66.2 (A), n0.2 (ROW)
unnamed: D67.2 (A), p-key1.2 (ROW)
unnamed: D68.2 (A), semicolon-key1.2 (ROW)
unnamed: D69.2 (A), dot-key1.2 (ROW)
unnamed: D70.2 (A), right-mod1-1.25U-key1.2 (ROW), right-mod2-1U-key1.2 (ROW)
unnamed: D71.2 (A), R3.1
unnamed: D72.2 (A), slash-key1.2 (ROW)
unnamed: D73.2 (A), pageup-Key1.2 (ROW)
unnamed: D74.2 (A), pagedown-Key1.2 (ROW)
unnamed: D75.2 (A), minus-key1.2 (ROW)
unnamed: D76.2 (A), leftbrace-key1.2 (ROW)
unnamed: D77.2 (A), apostrophe-key1.2 (ROW)
unnamed: D78.2 (A), right-mod1-1.5U-key1.2 (ROW), right-mod2-1.25U-key1.2 (ROW), right-mod3-1U-key1.2 (ROW)
unnamed: D79.2 (A), equal-key1.2 (ROW)
unnamed: D80.2 (A), rightbrace-key1.2 (ROW)
unnamed: D81.2 (A), NUHS-key1.2 (ROW)
unnamed: D82.2 (A), print-Key1.2 (ROW)
unnamed: D83.2 (A), scroll_lock-Key1.2 (ROW)
unnamed: D85.2 (A), right-mod1-1U-key1.2 (ROW)
unnamed: D87.2 (A), backspace1-key1.2 (ROW), backspace2-key1.2 (ROW)
unnamed: D88.2 (A), right_shift-1U-left-key1.2 (ROW), right_shift-2U-key1.2 (ROW)
unnamed: D89.2 (A), right-mod2-1.5U-key1.2 (ROW), right-mod3-1.25U-key1.2 (ROW), right-mod4-1U-key1.2 (ROW)
unnamed: D90.2 (A), numlock-Key1.2 (ROW)
unnamed: D91.2 (A), kp_#7-key1.2 (ROW)
unnamed: D93.2 (A), pipe-key1.2 (ROW)
unnamed: D94.2 (A), enter-ANSI-key1.2 (ROW), enter-ISO-key1.2 (ROW)
unnamed: D95.2 (A), right_shift-1U-right-key1.2 (ROW)
unnamed: D96.2 (A), arrow-left-key1.2 (ROW)
unnamed: D97.2 (A), kp_divide-key1.2 (ROW)
unnamed: D98.2 (A), kp_#8-key1.2 (ROW)
unnamed: D99.2 (A), kp_comma-key1.2 (ROW)
unnamed: D100.2 (A), arrow-up-key1.2 (ROW)
unnamed: D101.2 (A), kp_times-key1.2 (ROW)
unnamed: D102.2 (A), kp_#9-key1.2 (ROW)
unnamed: D103.2 (A), kp_#4-key1.2 (ROW)
unnamed: D104.2 (A), kp_#6-key1.2 (ROW)
unnamed: D105.2 (A), kp_#2-key1.2 (ROW)
unnamed: D106.2 (A), kp_#3-key1.2 (ROW)
unnamed: D107.2 (A), kp_#0-1U-left-key1.2 (ROW), kp_#0-2U-key1.2 (ROW)
unnamed: D109.2 (A), kp_plus1-key1.2 (ROW), kp_plus2-key1.2 (ROW)
unnamed: D110.2 (A), kp_#5-key1.2 (ROW)
unnamed: D111.2 (A), kp_plus-1U-down-key1.2 (ROW)
unnamed: D112.2 (A), kp_#2-key2.2 (ROW)
unnamed: D113.2 (A), kp_enter-1U-top-key1.2 (ROW), kp_enter-2U-key1.2 (ROW)
unnamed: D114.2 (A), kp_#0-1U-right-key1.2 (ROW)
unnamed: J2.A5 (CC1), R7.1
unnamed: J2.B5 (CC2), R8.2
NumLock: R1.2, U1.22 (PB11)
SWCLK: J1.2, U1.37 (PA14)
SWDIO: J1.3, U1.34 (PA13)
SWO: J1.4, U1.39 (PB3)
ScrollLock: R3.2, U1.2 (PC13)
VBUS: F1.1, J2.A4 (VBUS), J2.A9 (VBUS), J2.B4 (VBUS), J2.B9 (VBUS), U4.5 (VBUS)
buzzer+: BZ1.2 (-), U1.38 (PA15)
col0: NUBS-key1.1 (COL), U2.9 (I0), a-key1.1 (COL), capslock-standard-key1.1 (COL), capslock-stepped-key1.1 (COL), escape-Key1.1 (COL), grave-key1.1 (COL), left-mod1-1.5U-key1.1 (COL), left-mod1-1.25U-key1.1 (COL), left-mod1-1U-key1.1 (COL), left-mod2-1.5U-key1.1 (COL), left-mod2-1.25U-key1.1 (COL), left-mod2-1U-key1.1 (COL), left_shift-1.25U-key1.1 (COL), left_shift-2.25U-key1.1 (COL), n1.1 (COL), q-key1.1 (COL), tab-key1.1 (COL)
col1: U2.8 (I1), e-key1.1 (COL), f1-Key1.1 (COL), f2-Key1.1 (COL), f7-Key1.1 (COL), f8-Key1.1 (COL), key_d1.1 (COL), left-mod3-1.25U-key1.1 (COL), left-mod3-1U-key1.1 (COL), n2.1 (COL), n3.1 (COL), s-key1.1 (COL), w-key1.1 (COL), x-key1.1 (COL), z-key1.1 (COL)
col2: U2.7 (I2), c-key1.1 (COL), f3-Key1.1 (COL), f4-Key1.1 (COL), f9-Key1.1 (COL), f10-Key1.1 (COL), f-key1.1 (COL), g-key1.1 (COL), n4.1 (COL), n5.1 (COL), r-key1.1 (COL), t-key1.1 (COL), v-key1.1 (COL)
col3: U2.6 (I3), b-key1.1 (COL), f5-Key1.1 (COL), f6-Key1.1 (COL), f11-Key1.1 (COL), f12-Key1.1 (COL), h-key1.1 (COL), j-key1.1 (COL), n6.1 (COL), n7.1 (COL), n-key1.1 (COL), space-6.25-C-key1.1 (COL), space-6.25U-B-key1.1 (COL), space-6U1.1 (COL), space-6U/7U-key1.1 (COL), u-key1.1 (COL), y-key1.1 (COL)
col4: U2.5 (I4), arrow-down-key1.1 (COL), arrow-right-key1.1 (COL), comma-key1.1 (COL), delete-Key1.1 (COL), i-key1.1 (COL), insert-Key1.1 (COL), k-key1.1 (COL), l-key1.1 (COL), m-key1.1 (COL), n8.1 (COL), n9.1 (COL), o-key1.1 (COL)
col5: U2.4 (I5), apostrophe-key1.1 (COL), dot-key1.1 (COL), end-Key1.1 (COL), home-Key1.1 (COL), leftbrace-key1.1 (COL), minus-key1.1 (COL), n0.1 (COL), p-key1.1 (COL), pagedown-Key1.1 (COL), pageup-Key1.1 (COL), right-mod1-1.5U-key1.1 (COL), right-mod1-1.25U-key1.1 (COL), right-mod2-1.25U-key1.1 (COL), right-mod2-1U-key1.1 (COL), right-mod3-1U-key1.1 (COL), semicolon-key1.1 (COL), slash-key1.1 (COL)
col6: NUHS-key1.1 (COL), U2.3 (I6), backspace1-key1.1 (COL), backspace2-key1.1 (COL), equal-key1.1 (COL), kp_enter-1U-down-key1.1 (COL), pause-Key1.1 (COL), print-Key1.1 (COL), right-mod1-1U-key1.1 (COL), right-mod2-1.5U-key1.1 (COL), right-mod3-1.25U-key1.1 (COL), right-mod4-1U-key1.1 (COL), right_shift-1U-left-key1.1 (COL), right_shift-2U-key1.1 (COL), rightbrace-key1.1 (COL), scroll_lock-Key1.1 (COL)
col7: U2.2 (I7), arrow-left-key1.1 (COL), arrow-up-key1.1 (COL), backspace3-key1.1 (COL), enter-ANSI-key1.1 (COL), enter-ISO-key1.1 (COL), kp_#7-key1.1 (COL), kp_#8-key1.1 (COL), kp_comma-key1.1 (COL), kp_divide-key1.1 (COL), numlock-Key1.1 (COL), pipe-key1.1 (COL), right_shift-1U-right-key1.1 (COL)
col8: U2.23 (I8), kp_#0-1U-left-key1.1 (COL), kp_#0-1U-right-key1.1 (COL), kp_#0-2U-key1.1 (COL), kp_#2-key1.1 (COL), kp_#2-key2.1 (COL), kp_#3-key1.1 (COL), kp_#4-key1.1 (COL), kp_#5-key1.1 (COL), kp_#6-key1.1 (COL), kp_#9-key1.1 (COL), kp_enter-1U-top-key1.1 (COL), kp_enter-2U-key1.1 (COL), kp_minus-key1.1 (COL), kp_plus1-key1.1 (COL), kp_plus2-key1.1 (COL), kp_plus-1U-down-key1.1 (COL), kp_times-key1.1 (COL)
encA1_row5_d: D3.2 (A), grave-key1.2 (ROW)
encA2_row5_d: D92.2 (A), backspace3-key1.2 (ROW)
encB_row1_d: D86.2 (A), pause-Key1.2 (ROW)
encC1_row0_d: D108.2 (A), kp_minus-key1.2 (ROW)
encC2_row11_d: D84.2 (A), kp_enter-1U-down-key1.2 (ROW)
row0: D2.1 (K), D18.1 (K), D31.1 (K), D44.1 (K), D64.1 (K), D82.1 (K), D97.1 (K), D108.1 (K), U1.15 (PA5)
row1: D12.1 (K), D25.1 (K), D37.1 (K), D56.1 (K), D73.1 (K), D86.1 (K), D90.1 (K), D101.1 (K), U1.12 (PA2)
row2: D19.1 (K), D32.1 (K), D45.1 (K), D65.1 (K), D98.1 (K), D109.1 (K), U1.14 (PA4)
row3: D13.1 (K), D26.1 (K), D43.1 (K), D57.1 (K), D74.1 (K), D83.1 (K), D91.1 (K), D102.1 (K), U1.13 (PA3)
row4: D7.1 (K), D20.1 (K), D33.1 (K), D46.1 (K), D58.1 (K), D75.1 (K), D87.1 (K), D110.1 (K), U1.25 (PB12)
row5: D3.1 (K), D14.1 (K), D27.1 (K), D38.1 (K), D51.1 (K), D66.1 (K), D79.1 (K), D92.1 (K), D103.1 (K), U1.26 (PB13)
row6: D8.1 (K), D21.1 (K), D34.1 (K), D47.1 (K), D59.1 (K), D76.1 (K), D93.1 (K), D104.1 (K), U1.27 (PB14)
row7: D4.1 (K), D15.1 (K), D28.1 (K), D39.1 (K), D52.1 (K), D67.1 (K), D80.1 (K), D111.1 (K), U1.28 (PB15)
row8: D9.1 (K), D22.1 (K), D35.1 (K), D48.1 (K), D60.1 (K), D77.1 (K), D94.1 (K), D112.1 (K), U1.29 (PA8)
row9: D5.1 (K), D16.1 (K), D29.1 (K), D40.1 (K), D53.1 (K), D68.1 (K), D81.1 (K), D105.1 (K), U1.19 (PB1)
row10: D10.1 (K), D23.1 (K), D36.1 (K), D49.1 (K), D61.1 (K), D72.1 (K), D88.1 (K), D99.1 (K), D106.1 (K), U1.18 (PB0)
row11: D6.1 (K), D17.1 (K), D30.1 (K), D41.1 (K), D54.1 (K), D69.1 (K), D84.1 (K), D95.1 (K), D113.1 (K), U1.46 (PB9)
row12: D11.1 (K), D62.1 (K), D78.1 (K), D85.1 (K), D96.1 (K), D107.1 (K), U1.17 (PA7)
row13: D1.1 (K), D24.1 (K), D42.1 (K), D50.1 (K), D70.1 (K), D89.1 (K), D100.1 (K), D114.1 (K), U1.16 (PA6)
s0: U1.41 (PB5), U2.10 (S0)
s1: U1.42 (PB6), U2.11 (S1)
s2: U1.45 (PB8), U2.14 (S2)
s3: U1.43 (PB7), U2.13 (S3)
sig: U1.40 (PB4), U2.1 (COM)

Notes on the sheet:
Other
LEDs
Controller
PS/2 Interface
Power Flags
Voltage Step Down
USB-C
MUX
Buzzer
SWD Interface
ESD Protection
Mounting Holes
Connector
STM32F072CBT6
Bootloader Button
Decoupling Capacitors

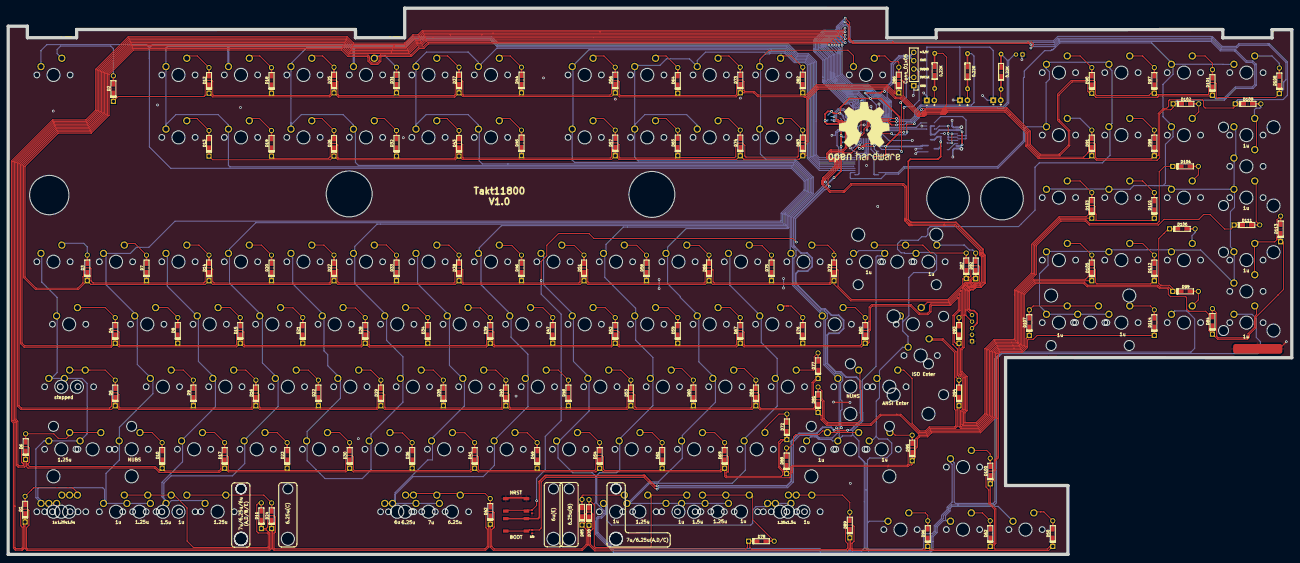
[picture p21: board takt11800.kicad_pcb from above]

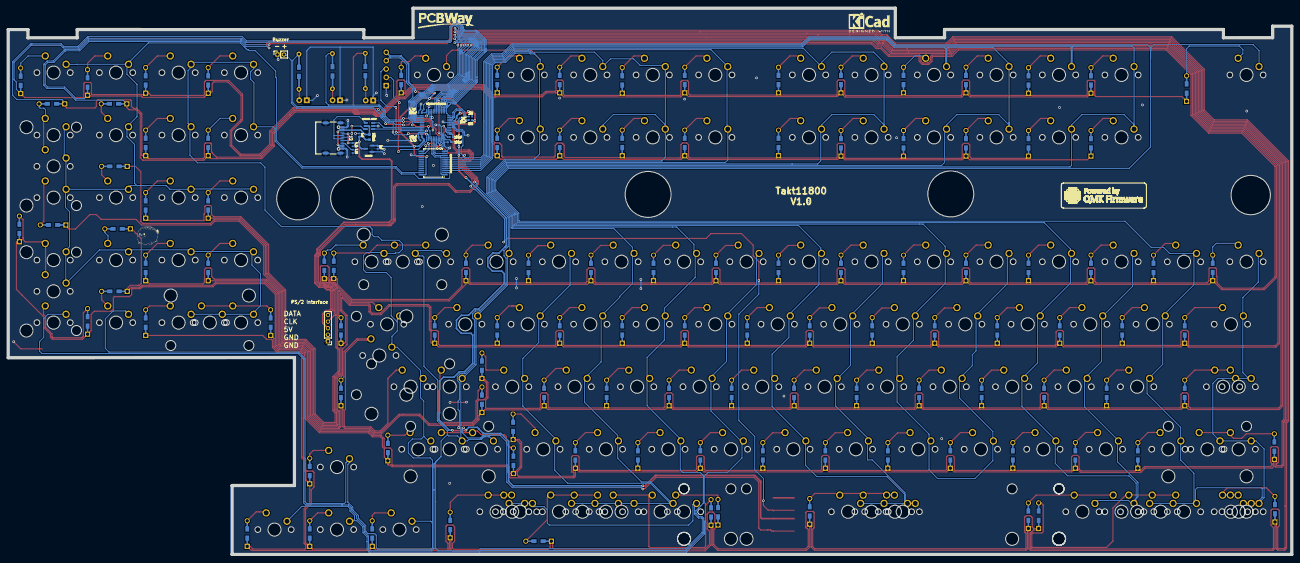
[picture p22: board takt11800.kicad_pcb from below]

Board: 2 copper layers, 391.2 x 166.5 mm, 282 parts (28 on the bottom side), 163 nets.

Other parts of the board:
Kicad: KiCad-Logo2_5mm_SilkScreen

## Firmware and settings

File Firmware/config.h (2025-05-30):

/*
Copyright 2024 BFB Workshop

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
You should have received a copy of the GNU General Public License
along with this program.  If not, see <http://www.gnu.org/licenses/>.
*/

#pragma once

#define DEBOUNCE 5

#define MATRIX_ROWS 14
#define MATRIX_COLS 9

#define BOOTMAGIC_LITE_ROW 0
#define BOOTMAGIC_LITE_COLUMN 0

#define DIODE_DIRECTION COL2ROW
#define ROW_PINS { A5, A2, A4, A3, B12, B13, B14, B15, A8, B1, B0, B9, A7, A6 }
#define COL_PINS { NO_PIN, NO_PIN, NO_PIN, NO_PIN, NO_PIN, NO_PIN, NO_PIN, NO_PIN, NO_PIN }

/*############## PS2 Mouse ##################*/

# define PS2_CLOCK_PIN   A0
# define PS2_DATA_PIN    A1

/*###########################################*/

/*############## LEDs ##################*/

#define LED_NUM_LOCK_PIN  B11
#define LED_CAPS_LOCK_PIN B10
#define LAYER_LED         C13 // #define LED_SCROLL_LOCK_PIN B3

/*######################################*/

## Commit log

2025-04-25 Refactor PCB and firmware structure; update docs, assets, and remove legacy files
    [takt11800-B_Courtyard.gbr, takt11800-B_Cu.gbl, takt11800-B_Fab.gbr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]
2025-07-03 update USB-C footprint; adjust arrow keys position; cleanup libraries
    [takt11800.kicad_pcb, takt11800.kicad_sch]
2025-12-21 update Readme, add BOM and CPL
    [takt11800_BOM.csv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]
2025-12-21 fix BOM csv formatting
    [takt11800_BOM.csv]

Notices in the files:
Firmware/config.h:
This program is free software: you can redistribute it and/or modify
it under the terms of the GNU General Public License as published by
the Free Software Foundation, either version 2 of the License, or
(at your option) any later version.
